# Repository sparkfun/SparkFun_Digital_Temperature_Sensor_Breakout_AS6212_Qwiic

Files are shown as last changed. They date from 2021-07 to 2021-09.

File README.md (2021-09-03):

SparkFun Digital Temperature Sensor Breakout - AS6212 (Qwiic)
========================================

SparkFun Digital Temperature Sensor Breakout - AS6212 (Qwiic) (https://www.sparkfun.com/products/18521)

[*SparkFun Digital Temperature Sensor Breakout - AS6212 (Qwiic)(SEN-18521)*](https://www.sparkfun.com/products/18521)

The AS6212 provides a combination of high temperature accuracy with excellent low power consumption using the AS6212 digital temperature sensor from ams AG. The AS6212 measures temperature with &plusmn;0.2&deg;C accuracy between -10&deg;C to 65&deg;C, consumes an average of 6&micro;A (0.1&micro;A in standby) and communicates over I<sup>2</sup>C so naturally we put it on a Qwiic breakout to add to our ever expanding Qwiic system. The sensor boasts a host of features including a configurable alert pin that can trigger when temperature data exceeds user-defined temperature thresholds. All of this in a tiny IC package measuring 1.5mm x 1mm.

The AD0 and AD1 jumpers control the I<sup>2</sup>C address as well as enabling/disabling the Alert pin. By default, these two-way jumpers connect the AD0 pin to Ground and the Alert/AD1 pin to 3.3V to enable the Alert pin and set the I<sup>2</sup>C address to 0x48. These jumpers control the address and enable/disable the Alert pin.

Repository Contents
-------------------

* **/Documentation** - Data sheets, additional product information
* **/Hardware** - Eagle design files (.brd, .sch)
* **/Production** - Production panel files (.brd)

Documentation
--------------

* **[Installing an Arduino Library Guide](https://learn.sparkfun.com/tutorials/installing-an-arduino-library)** - Basic information on how to install an Arduino library.
* **[SparkFun AS6212 Qwiic Arduino Library](https://github.com/sparkfun/SparkFun_AS6212_Qwiic_Arduino_Library)** - Arduino library for the SparkFun Digital Temperature Sensor Breakout - AS6212 (Qwiic).
* **[Qwiic AS6212 Py](https://github.com/sparkfun/Qwiic_AS6212_Py)** - Python module for the SparkFun Digital Temperature Sensor Breakout - AS6212 (Qwiic).
* **[Hookup Guide](https://learn.sparkfun.com/tutorials/digital-temperature-sensor-breakout---as6212-qwiic-hookup-guide)** - Basic hookup guide for the SparkFun Digital Temperature Sensor Breakout - AS6212 (Qwiic).

Version History
---------------

* [SEN-18521](https://www.sparkfun.com/products/18521) - Initial release of the SparkFun Digital Temperature Sensor Breakout - AS6212 (Qwiic).

License Information
-------------------

This product is _**open source**_! 

Please review the LICENSE.md file for license information. 

If you have any questions or concerns on licensing, please contact technical support on our [SparkFun forums](https://forum.sparkfun.com/viewforum.php?f=152).

Distributed as-is; no warranty is given.

- Your friends at SparkFun.

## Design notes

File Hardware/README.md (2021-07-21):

SparkFun High Precision Temperature Sensor TMP117 (Qwiic) Design Files
=====================================

The .sch and .brd files hare are Eagle CAD schematic and PCB design files from SparkFun Electronics.
A freeware version of Eagle can be found [here](http://www.cadsoftusa.com/download-eagle/freeware/).

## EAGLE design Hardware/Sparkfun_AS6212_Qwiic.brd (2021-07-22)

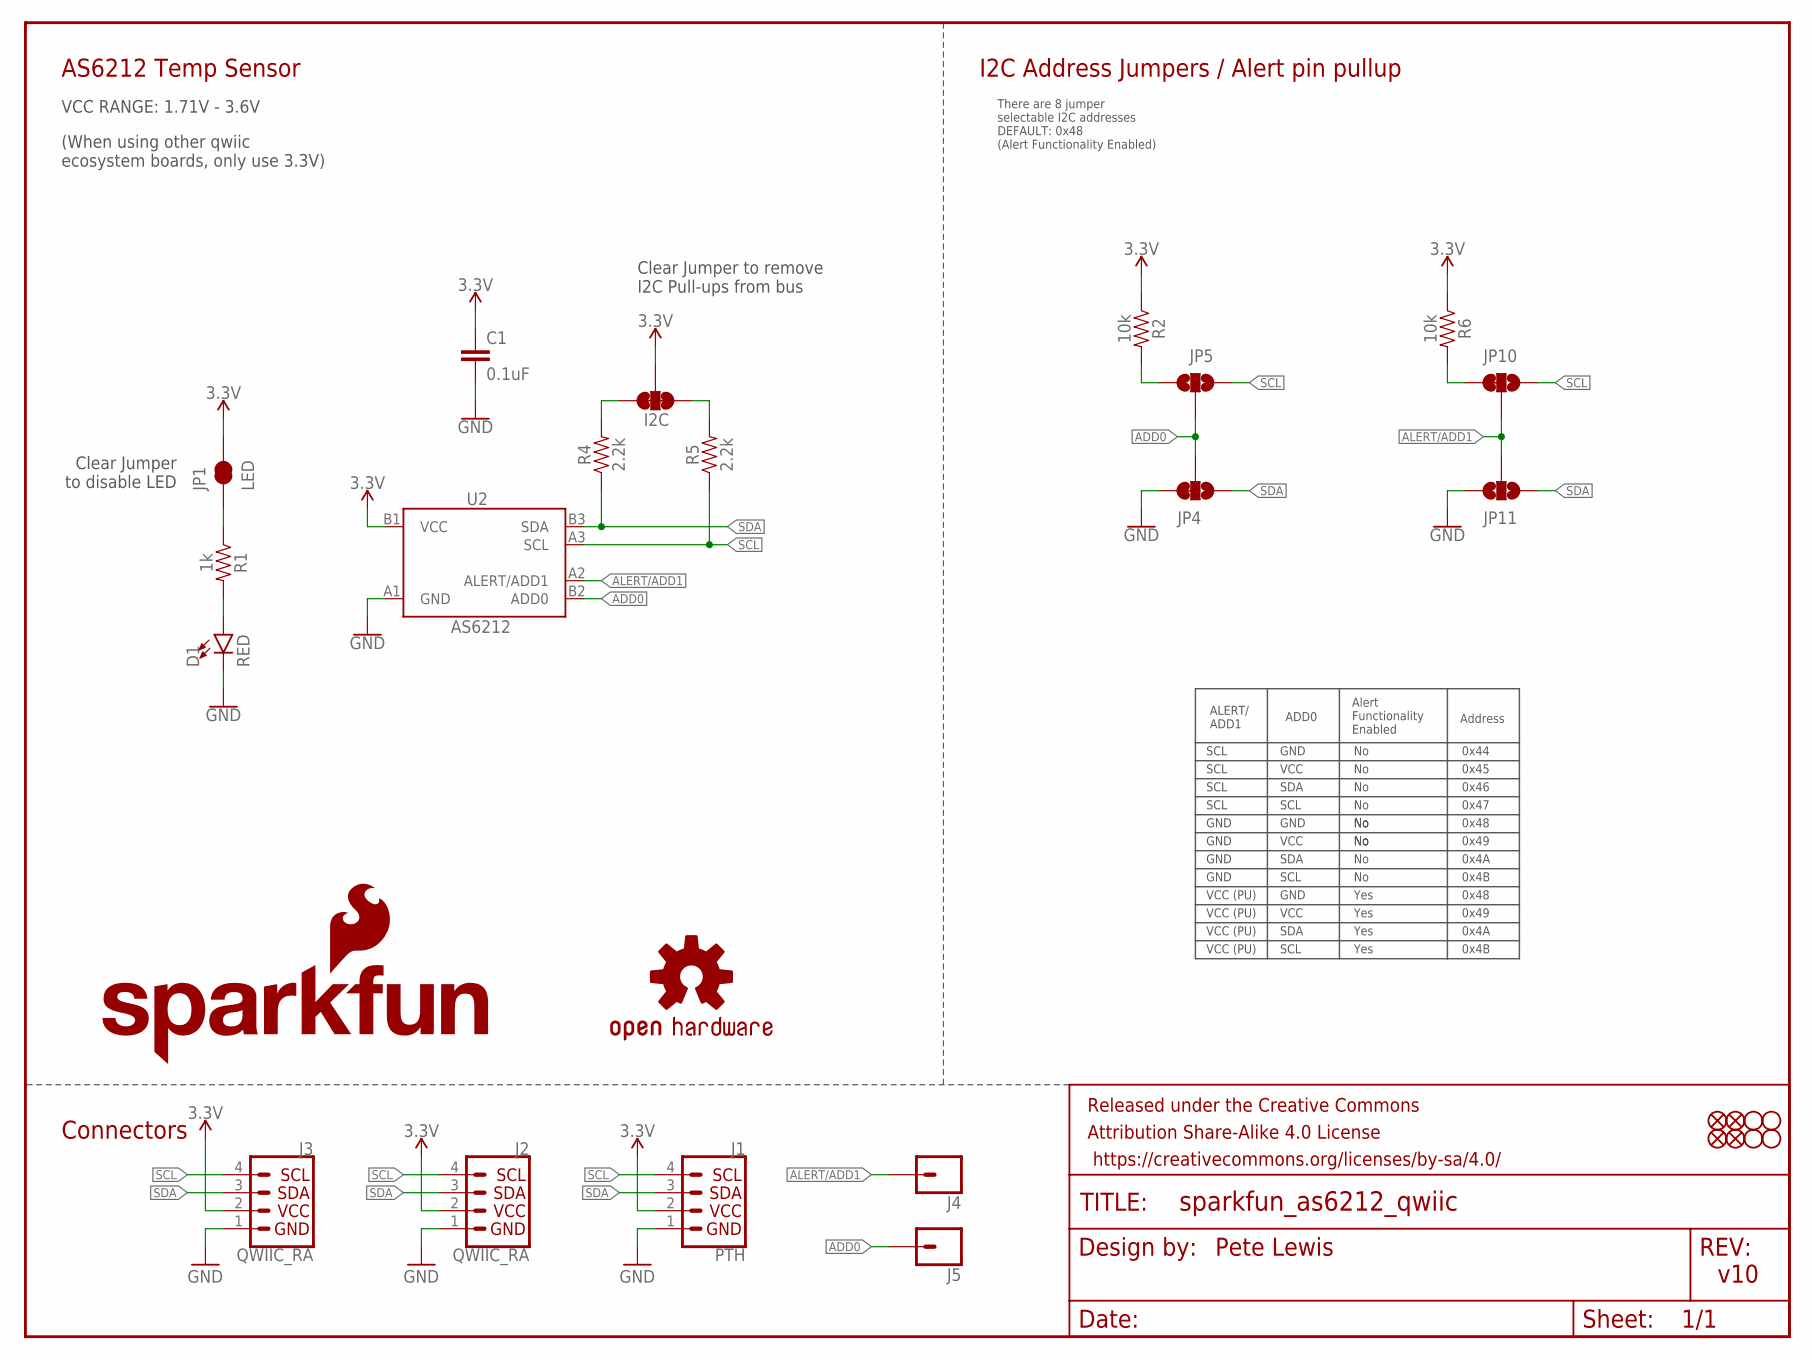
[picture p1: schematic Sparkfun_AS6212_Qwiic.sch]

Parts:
C1: 0.1uF; 0603
D1: RED; LED-0603
FD1, FD2, FD3, FD4: FIDUCIALUFIDUCIAL; FIDUCIAL-MICRO
FRAME1: FRAME-LETTER; CREATIVE_COMMONS
I2C: JUMPER-SMT_3_2-NC_TRACE_SILK; SMT-JUMPER_3_2-NC_TRACE_SILK
J1: PTH; 1X04_NO_SILK
J2, J3: QWIIC_RA; JST04_1MM_RA
J4, J5: CONN_01PTH_NO_SILK_YES_STOP; 1X01_NO_SILK
JP1: LED; SMT-JUMPER_2_NC_TRACE_SILK
JP2, JP3, JP8, JP9: STAND-OFF
JP4, JP10: JUMPER-SMT_3_1-NC_TRACE_NO-SILK; SMT-JUMPER_3_1-NC_TRACE_NO-SILK
JP5, JP11: JUMPER-SMT_3_NO_NO_SILK; SMT-JUMPER_3_0-NO_TRACE_NO-SILK
LOGO1: OSHW-LOGOMINI; OSHW-LOGO-MINI
LOGO4: SFE_LOGO_NAME_FLAME.1_INCH; SFE_LOGO_NAME_FLAME_.1
R1: 1k; 0603
R2, R6: 10k; 0603
R4, R5: 2.2k; 0603
U2: AS6212; WLCSP

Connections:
3.3V: C1.1, I2C.2, J1.2, J2.2, J3.2, JP1.2, R2.1, R6.1, U2.B1 (VCC)
ADD0: J5.1, JP4.2, JP5.2, U2.B2 (ADD0)
ALERT/ADD1: J4.1, JP10.2, JP11.2, U2.A2 (ALERT/ADD1)
GND: C1.2, D1.C, J1.1, J2.1, J3.1, JP4.3, JP11.3, U2.A1 (GND)
unnamed: D1.A, R1.2
unnamed: I2C.1, R5.2
unnamed: I2C.3, R4.2
unnamed: JP10.3, R6.2
unnamed: JP5.1, R2.2
unnamed: JP1.1, R1.1
SCL: J1.4, J2.4, J3.4, JP5.3, JP10.1, R5.1, U2.A3 (SCL)
SDA: J1.3, J2.3, J3.3, JP4.1, JP11.1, R4.1, U2.B3 (SDA)

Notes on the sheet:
Pete Lewis
Clear Jumper to remove I2C Pull-ups from bus
v10
There are 8 jumper selectable I2C addresses DEFAULT: 0x48 (Alert Functionality Enabled)
Alert Functionality Enabled
SCL
Clear Jumper to disable LED
VCC RANGE: 1.71V - 3.6V
(When using other qwiic ecosystem boards, only use 3.3V)
AS6212 Temp Sensor
I2C Address Jumpers / Alert pin pullup
Connectors
VCC (PU)
GND
ALERT/ ADD1
ADD0
SDA
VCC
Yes
Address
0x44
0x45
0x46
0x49
0x4A
0x4B
0x47
0x48

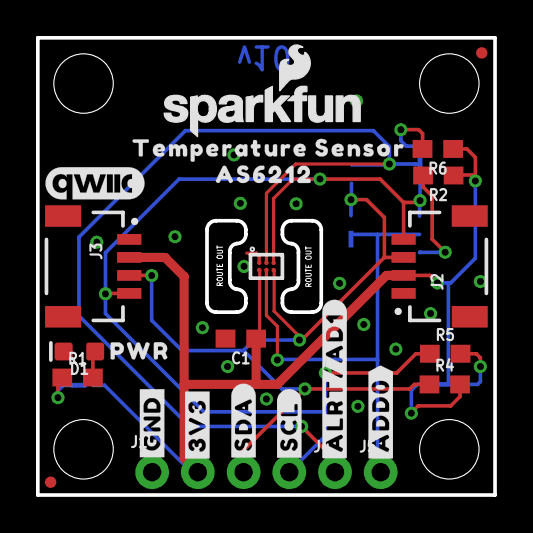
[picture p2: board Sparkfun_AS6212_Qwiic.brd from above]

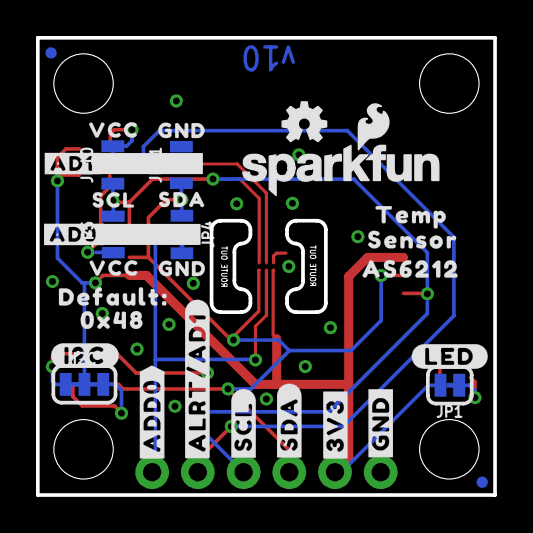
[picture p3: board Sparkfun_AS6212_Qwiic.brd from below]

Board: 2 copper layers, 25.4 x 25.4 mm, 62 parts (31 on the bottom side), 12 nets.

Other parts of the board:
LOGO2: SFE_LOGO_NAME_FLAME.1_INCH; SFE_LOGO_NAME_FLAME_.1
U$1: #LED#10
U$2: #I2C#11
U$3, U$25: AS62128
U$4: #AD0#1
U$5: #AD1#1
U$6: SCL3
U$7, U$13: VCC4
U$8: DEFAULT#11
U$9, U$14: GND5
U$10: SDA6
U$11, U$12: #ALRT#AD1#12
U$15: QWIIC_5.5MM
U$16: SENSOR8
U$17: TEMP9
U$18: 0X4812
U$19: PWR12
U$20, U$21: #3V3#13
U$24: TEMPERATURE_SENSOR7
U$26, U$30: #GND#62130
U$28, U$34: #SDA#62131
U$29, U$35: #SCL#62132
U$31, U$36: #ADD0#0

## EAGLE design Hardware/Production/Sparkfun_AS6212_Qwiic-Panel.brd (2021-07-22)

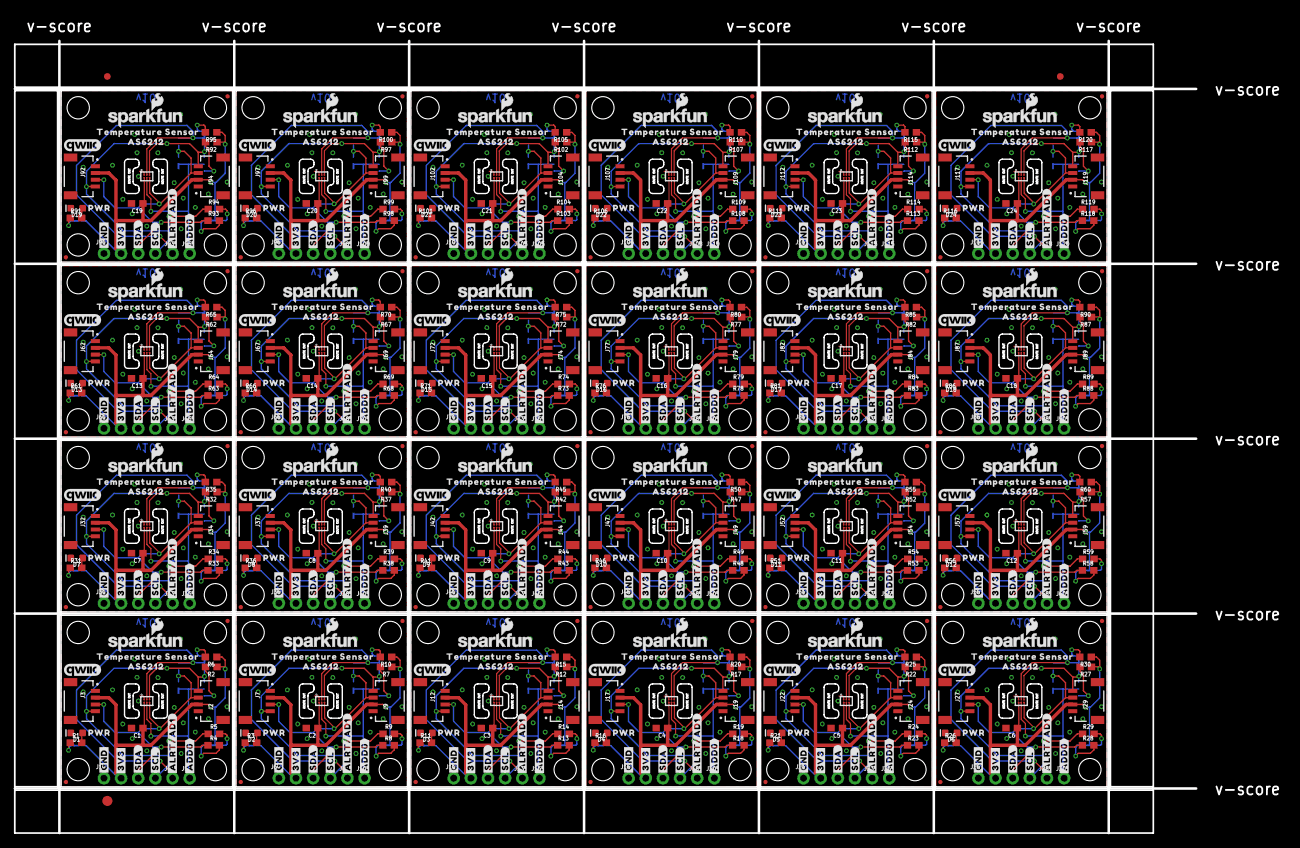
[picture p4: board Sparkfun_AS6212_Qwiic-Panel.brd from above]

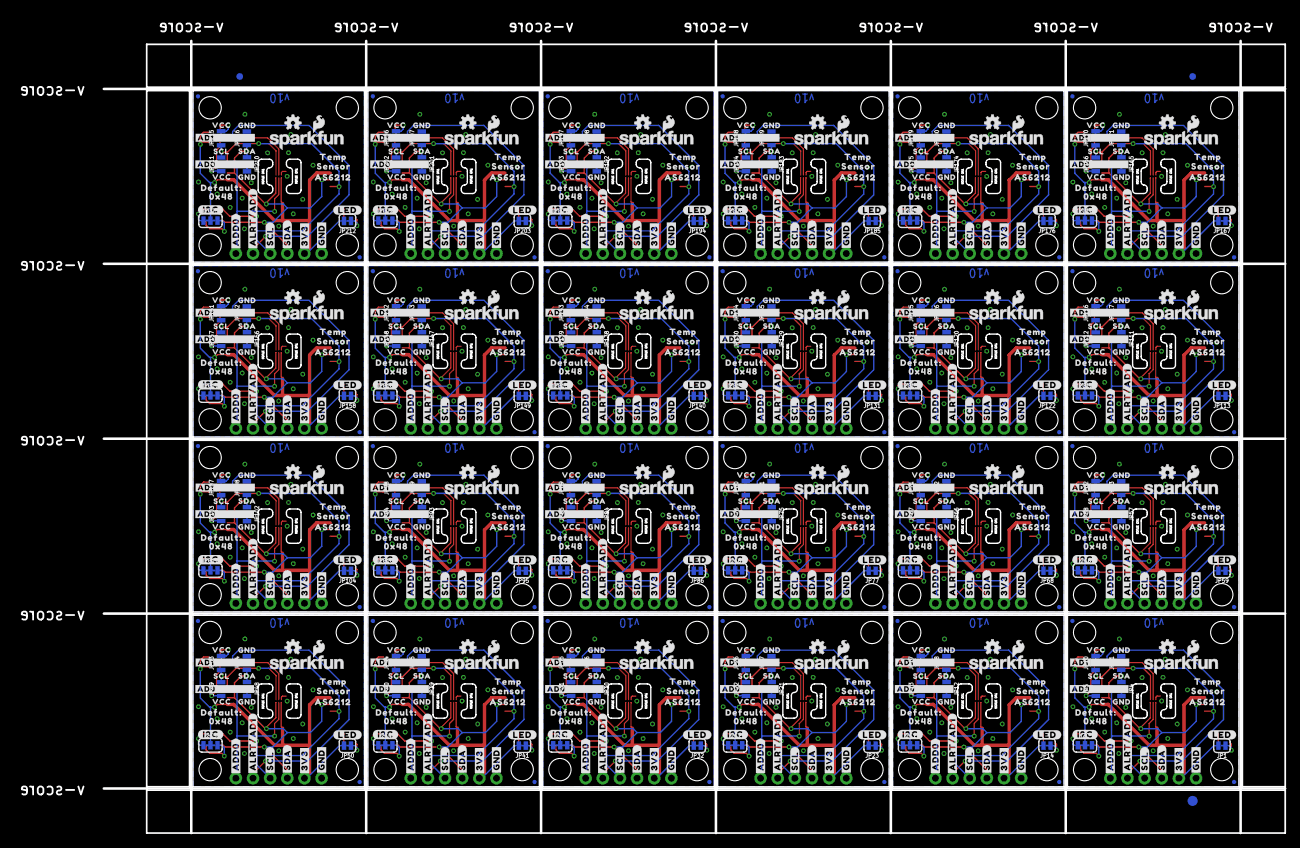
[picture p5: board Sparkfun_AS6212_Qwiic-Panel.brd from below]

Board: 2 copper layers, 175.0 x 117.3 mm, 1470 parts (747 on the bottom side), 288 nets.

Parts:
C1, C2, C3, C4, C5, C6, C7, C8, C9, C10, C11, C12, C13, C14, C15, C16, C17, C18, C19, C20, C21, C22, C23, C24: 0.1uF; 0603
D1, D2, D3, D4, D5, D6, D7, D8, D9, D10, D11, D12, D13, D14, D15, D16, D17, D18, D19, D20, D21, D22, D23, D24: RED; LED-0603
E$1, E$2, E$3, E$4: FIDUCIAL-1X2
E$5, E$6: FIDUCIAL-1.5X3
FD1, FD2, FD3, FD4, FD5, FD6, FD7, FD8, FD9, FD10, FD11, FD12, FD13, FD14, FD15, FD16, FD17, FD18, FD19, FD20, FD21, FD22, FD23, FD24, FD25, FD26, FD27, FD28, FD29, FD30, FD31, FD32, FD33, FD34, FD35, FD36, FD37, FD38, FD39, FD40, FD41, FD42, FD43, FD44, FD45, FD46, FD47, FD48, FD49, FD50, FD51, FD52, FD53, FD54, FD55, FD56, FD57, FD58, FD59, FD60, FD61, FD62, FD63, FD64, FD65, FD66, FD67, FD68, FD69, FD70, FD71, FD72, FD73, FD74, FD75, FD76, FD77, FD78, FD79, FD80, FD81, FD82, FD83, FD84, FD85, FD86, FD87, FD88, FD89, FD90, FD91, FD92, FD93, FD94, FD95, FD96: FIDUCIALUFIDUCIAL; FIDUCIAL-MICRO
I2C, I2C1, I2C2, I2C3, I2C4, I2C5, I2C6, I2C7, I2C8, I2C9, I2C10, I2C11, I2C12, I2C13, I2C14, I2C15, I2C16, I2C17, I2C18, I2C19, I2C20, I2C21, I2C22, I2C23: SMT-JUMPER_3_2-NC_TRACE_SILK
J1, J6, J11, J16, J21, J26, J31, J36, J41, J46, J51, J56, J61, J66, J71, J76, J81, J86, J91, J96, J101, J106, J111, J116: PTH; 1X04_NO_SILK
J2, J3, J7, J9, J12, J14, J17, J19, J22, J24, J27, J29, J32, J34, J37, J39, J42, J44, J47, J49, J52, J54, J57, J59, J62, J64, J67, J69, J72, J74, J77, J79, J82, J84, J87, J89, J92, J94, J97, J99, J102, J104, J107, J109, J112, J114, J117, J119: QWIIC_RA; JST04_1MM_RA
J4, J5, J8, J10, J13, J15, J18, J20, J23, J25, J28, J30, J33, J35, J38, J40, J43, J45, J48, J50, J53, J55, J58, J60, J63, J65, J68, J70, J73, J75, J78, J80, J83, J85, J88, J90, J93, J95, J98, J100, J103, J105, J108, J110, J113, J115, J118, J120: 1X01_NO_SILK
JP1, JP14, JP23, JP32, JP41, JP50, JP59, JP68, JP77, JP86, JP95, JP104, JP113, JP122, JP131, JP140, JP149, JP158, JP167, JP176, JP185, JP194, JP203, JP212: LED; SMT-JUMPER_2_NC_TRACE_SILK
JP2, JP3, JP6, JP7, JP8, JP9, JP15, JP16, JP19, JP20, JP24, JP25, JP28, JP29, JP33, JP34, JP37, JP38, JP42, JP43, JP46, JP47, JP51, JP52, JP55, JP56, JP60, JP61, JP64, JP65, JP69, JP70, JP73, JP74, JP78, JP79, JP82, JP83, JP87, JP88, JP91, JP92, JP96, JP97, JP100, JP101, JP105, JP106, JP109, JP110, JP114, JP115, JP118, JP119, JP123, JP124, JP127, JP128, JP132, JP133, JP136, JP137, JP141, JP142, JP145, JP146, JP150, JP151, JP154, JP155, JP159, JP160, JP163, JP164, JP168, JP169, JP172, JP173, JP177, JP178, JP181, JP182, JP186, JP187, JP190, JP191, JP195, JP196, JP199, JP200, JP204, JP205, JP208, JP209, JP213, JP214: STAND-OFF
JP4, JP10, JP12, JP17, JP21, JP26, JP30, JP35, JP39, JP44, JP48, JP53, JP57, JP62, JP66, JP71, JP75, JP80, JP84, JP89, JP93, JP98, JP102, JP107, JP111, JP116, JP120, JP125, JP129, JP134, JP138, JP143, JP147, JP152, JP156, JP161, JP165, JP170, JP174, JP179, JP183, JP188, JP192, JP197, JP201, JP206, JP210, JP215: JUMPER-SMT_3_1-NC_TRACE_NO-SILK; SMT-JUMPER_3_1-NC_TRACE_NO-SILK
JP5, JP11, JP13, JP18, JP22, JP27, JP31, JP36, JP40, JP45, JP49, JP54, JP58, JP63, JP67, JP72, JP76, JP81, JP85, JP90, JP94, JP99, JP103, JP108, JP112, JP117, JP121, JP126, JP130, JP135, JP139, JP144, JP148, JP153, JP157, JP162, JP166, JP171, JP175, JP180, JP184, JP189, JP193, JP198, JP202, JP207, JP211, JP216: JUMPER-SMT_3_NO_NO_SILK; SMT-JUMPER_3_0-NO_TRACE_NO-SILK
LOGO1, LOGO3, LOGO7, LOGO10, LOGO13, LOGO16, LOGO19, LOGO22, LOGO25, LOGO28, LOGO31, LOGO34, LOGO37, LOGO40, LOGO43, LOGO46, LOGO49, LOGO52, LOGO55, LOGO58, LOGO61, LOGO64, LOGO67, LOGO70: OSHW-LOGOMINI; OSHW-LOGO-MINI
LOGO2, LOGO4, LOGO5, LOGO6, LOGO8, LOGO9, LOGO11, LOGO12, LOGO14, LOGO15, LOGO17, LOGO18, LOGO20, LOGO21, LOGO23, LOGO24, LOGO26, LOGO27, LOGO29, LOGO30, LOGO32, LOGO33, LOGO35, LOGO36, LOGO38, LOGO39, LOGO41, LOGO42, LOGO44, LOGO45, LOGO47, LOGO48, LOGO50, LOGO51, LOGO53, LOGO54, LOGO56, LOGO57, LOGO59, LOGO60, LOGO62, LOGO63, LOGO65, LOGO66, LOGO68, LOGO69, LOGO71, LOGO72: SFE_LOGO_NAME_FLAME.1_INCH; SFE_LOGO_NAME_FLAME_.1
R1, R3, R11, R16, R21, R26, R31, R36, R41, R46, R51, R56, R61, R66, R71, R76, R81, R86, R91, R96, R101, R106, R111, R116: 1k; 0603
R2, R6, R7, R10, R12, R15, R17, R20, R22, R25, R27, R30, R32, R35, R37, R40, R42, R45, R47, R50, R52, R55, R57, R60, R62, R65, R67, R70, R72, R75, R77, R80, R82, R85, R87, R90, R92, R95, R97, R100, R102, R105, R107, R110, R112, R115, R117, R120: 10k; 0603
R4, R5, R8, R9, R13, R14, R18, R19, R23, R24, R28, R29, R33, R34, R38, R39, R43, R44, R48, R49, R53, R54, R58, R59, R63, R64, R68, R69, R73, R74, R78, R79, R83, R84, R88, R89, R93, R94, R98, R99, R103, R104, R108, R109, R113, R114, R118, R119: 2.2k; 0603
U1, U2, U3, U4, U5, U6, U7, U8, U9, U10, U11, U12, U13, U14, U15, U16, U17, U18, U19, U20, U21, U22, U23, U24: AS6212; WLCSP
U$1, U$54, U$85, U$116, U$147, U$178, U$209, U$240, U$271, U$302, U$333, U$364, U$395, U$426, U$457, U$488, U$519, U$550, U$581, U$612, U$643, U$674, U$705, U$736: #LED#10
U$2, U$55, U$86, U$117, U$148, U$179, U$210, U$241, U$272, U$303, U$334, U$365, U$396, U$427, U$458, U$489, U$520, U$551, U$582, U$613, U$644, U$675, U$706, U$737: #I2C#11
U$3, U$25, U$27, U$43, U$65, U$74, U$96, U$105, U$127, U$136, U$158, U$167, U$189, U$198, U$220, U$229, U$251, U$260, U$282, U$291, U$313, U$322, U$344, U$353, U$375, U$384, U$406, U$415, U$437, U$446, U$468, U$477, U$499, U$508, U$530, U$539, U$561, U$570, U$592, U$601, U$623, U$632, U$654, U$663, U$685, U$694, U$716, U$725: AS62128
U$4, U$44, U$75, U$106, U$137, U$168, U$199, U$230, U$261, U$292, U$323, U$354, U$385, U$416, U$447, U$478, U$509, U$540, U$571, U$602, U$633, U$664, U$695, U$726: #AD0#1
U$5, U$45, U$76, U$107, U$138, U$169, U$200, U$231, U$262, U$293, U$324, U$355, U$386, U$417, U$448, U$479, U$510, U$541, U$572, U$603, U$634, U$665, U$696, U$727: #AD1#1
U$6, U$46, U$77, U$108, U$139, U$170, U$201, U$232, U$263, U$294, U$325, U$356, U$387, U$418, U$449, U$480, U$511, U$542, U$573, U$604, U$635, U$666, U$697, U$728: SCL3
U$7, U$13, U$47, U$50, U$78, U$81, U$109, U$112, U$140, U$143, U$171, U$174, U$202, U$205, U$233, U$236, U$264, U$267, U$295, U$298, U$326, U$329, U$357, U$360, U$388, U$391, U$419, U$422, U$450, U$453, U$481, U$484, U$512, U$515, U$543, U$546, U$574, U$577, U$605, U$608, U$636, U$639, U$667, U$670, U$698, U$701, U$729, U$732: VCC4
U$8, U$56, U$87, U$118, U$149, U$180, U$211, U$242, U$273, U$304, U$335, U$366, U$397, U$428, U$459, U$490, U$521, U$552, U$583, U$614, U$645, U$676, U$707, U$738: DEFAULT#11
U$9, U$14, U$48, U$51, U$79, U$82, U$110, U$113, U$141, U$144, U$172, U$175, U$203, U$206, U$234, U$237, U$265, U$268, U$296, U$299, U$327, U$330, U$358, U$361, U$389, U$392, U$420, U$423, U$451, U$454, U$482, U$485, U$513, U$516, U$544, U$547, U$575, U$578, U$606, U$609, U$637, U$640, U$668, U$671, U$699, U$702, U$730, U$733: GND5
U$10, U$49, U$80, U$111, U$142, U$173, U$204, U$235, U$266, U$297, U$328, U$359, U$390, U$421, U$452, U$483, U$514, U$545, U$576, U$607, U$638, U$669, U$700, U$731: SDA6
U$11, U$12, U$58, U$59, U$89, U$90, U$120, U$121, U$151, U$152, U$182, U$183, U$213, U$214, U$244, U$245, U$275, U$276, U$306, U$307, U$337, U$338, U$368, U$369, U$399, U$400, U$430, U$431, U$461, U$462, U$492, U$493, U$523, U$524, U$554, U$555, U$585, U$586, U$616, U$617, U$647, U$648, U$678, U$679, U$709, U$710, U$740, U$741: #ALRT#AD1#12
U$15, U$22, U$63, U$94, U$125, U$156, U$187, U$218, U$249, U$280, U$311, U$342, U$373, U$404, U$435, U$466, U$497, U$528, U$559, U$590, U$621, U$652, U$683, U$714: QWIIC_5.5MM
U$16, U$52, U$83, U$114, U$145, U$176, U$207, U$238, U$269, U$300, U$331, U$362, U$393, U$424, U$455, U$486, U$517, U$548, U$579, U$610, U$641, U$672, U$703, U$734: SENSOR8
U$17, U$53, U$84, U$115, U$146, U$177, U$208, U$239, U$270, U$301, U$332, U$363, U$394, U$425, U$456, U$487, U$518, U$549, U$580, U$611, U$642, U$673, U$704, U$735: TEMP9
U$18, U$57, U$88, U$119, U$150, U$181, U$212, U$243, U$274, U$305, U$336, U$367, U$398, U$429, U$460, U$491, U$522, U$553, U$584, U$615, U$646, U$677, U$708, U$739: 0X4812
U$19, U$60, U$91, U$122, U$153, U$184, U$215, U$246, U$277, U$308, U$339, U$370, U$401, U$432, U$463, U$494, U$525, U$556, U$587, U$618, U$649, U$680, U$711, U$742: PWR12
U$20, U$21, U$61, U$62, U$92, U$93, U$123, U$124, U$154, U$155, U$185, U$186, U$216, U$217, U$247, U$248, U$278, U$279, U$309, U$310, U$340, U$341, U$371, U$372, U$402, U$403, U$433, U$434, U$464, U$465, U$495, U$496, U$526, U$527, U$557, U$558, U$588, U$589, U$619, U$620, U$650, U$651, U$681, U$682, U$712, U$713, U$743, U$744: #3V3#13
U$23, U$24, U$64, U$95, U$126, U$157, U$188, U$219, U$250, U$281, U$312, U$343, U$374, U$405, U$436, U$467, U$498, U$529, U$560, U$591, U$622, U$653, U$684, U$715: TEMPERATURE_SENSOR7
U$26, U$30, U$32, U$39, U$66, U$70, U$97, U$101, U$128, U$132, U$159, U$163, U$190, U$194, U$221, U$225, U$252, U$256, U$283, U$287, U$314, U$318, U$345, U$349, U$376, U$380, U$407, U$411, U$438, U$442, U$469, U$473, U$500, U$504, U$531, U$535, U$562, U$566, U$593, U$597, U$624, U$628, U$655, U$659, U$686, U$690, U$717, U$721: #GND#62130
U$28, U$33, U$34, U$40, U$67, U$71, U$98, U$102, U$129, U$133, U$160, U$164, U$191, U$195, U$222, U$226, U$253, U$257, U$284, U$288, U$315, U$319, U$346, U$350, U$377, U$381, U$408, U$412, U$439, U$443, U$470, U$474, U$501, U$505, U$532, U$536, U$563, U$567, U$594, U$598, U$625, U$629, U$656, U$660, U$687, U$691, U$718, U$722: #SDA#62131
U$29, U$35, U$37, U$41, U$68, U$72, U$99, U$103, U$130, U$134, U$161, U$165, U$192, U$196, U$223, U$227, U$254, U$258, U$285, U$289, U$316, U$320, U$347, U$351, U$378, U$382, U$409, U$413, U$440, U$444, U$471, U$475, U$502, U$506, U$533, U$537, U$564, U$568, U$595, U$599, U$626, U$630, U$657, U$661, U$688, U$692, U$719, U$723: #SCL#62132
U$31, U$36, U$38, U$42, U$69, U$73, U$100, U$104, U$131, U$135, U$162, U$166, U$193, U$197, U$224, U$228, U$255, U$259, U$286, U$290, U$317, U$321, U$348, U$352, U$379, U$383, U$410, U$414, U$441, U$445, U$472, U$476, U$503, U$507, U$534, U$538, U$565, U$569, U$596, U$600, U$627, U$631, U$658, U$662, U$689, U$693, U$720, U$724: #ADD0#0

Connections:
3.3V: C1.1, I2C.2, J1.2, J2.2, J3.2, JP1.2, R2.1, R6.1, U2.B1
3.3V1: C2.1, I2C1.2, J6.2, J7.2, J9.2, JP14.2, R7.1, R10.1, U1.B1
3.3V2: C3.1, I2C2.2, J11.2, J12.2, J14.2, JP23.2, R12.1, R15.1, U3.B1
3.3V3: C4.1, I2C3.2, J16.2, J17.2, J19.2, JP32.2, R17.1, R20.1, U4.B1
3.3V4: C5.1, I2C4.2, J21.2, J22.2, J24.2, JP41.2, R22.1, R25.1, U5.B1
3.3V5: C6.1, I2C5.2, J26.2, J27.2, J29.2, JP50.2, R27.1, R30.1, U6.B1
3.3V6: C7.1, I2C6.2, J31.2, J32.2, J34.2, JP59.2, R32.1, R35.1, U7.B1
3.3V7: C8.1, I2C7.2, J36.2, J37.2, J39.2, JP68.2, R37.1, R40.1, U8.B1
3.3V8: C9.1, I2C8.2, J41.2, J42.2, J44.2, JP77.2, R42.1, R45.1, U9.B1
3.3V9: C10.1, I2C9.2, J46.2, J47.2, J49.2, JP86.2, R47.1, R50.1, U10.B1
3.3V10: C11.1, I2C10.2, J51.2, J52.2, J54.2, JP95.2, R52.1, R55.1, U11.B1
3.3V11: C12.1, I2C11.2, J56.2, J57.2, J59.2, JP104.2, R57.1, R60.1, U12.B1
3.3V12: C13.1, I2C12.2, J61.2, J62.2, J64.2, JP113.2, R62.1, R65.1, U13.B1
3.3V13: C14.1, I2C13.2, J66.2, J67.2, J69.2, JP122.2, R67.1, R70.1, U14.B1
3.3V14: C15.1, I2C14.2, J71.2, J72.2, J74.2, JP131.2, R72.1, R75.1, U15.B1
3.3V15: C16.1, I2C15.2, J76.2, J77.2, J79.2, JP140.2, R77.1, R80.1, U16.B1
3.3V16: C17.1, I2C16.2, J81.2, J82.2, J84.2, JP149.2, R82.1, R85.1, U17.B1
3.3V17: C18.1, I2C17.2, J86.2, J87.2, J89.2, JP158.2, R87.1, R90.1, U18.B1
3.3V18: C19.1, I2C18.2, J91.2, J92.2, J94.2, JP167.2, R92.1, R95.1, U19.B1
3.3V19: C20.1, I2C19.2, J96.2, J97.2, J99.2, JP176.2, R97.1, R100.1, U20.B1
3.3V20: C21.1, I2C20.2, J101.2, J102.2, J104.2, JP185.2, R102.1, R105.1, U21.B1
3.3V21: C22.1, I2C21.2, J106.2, J107.2, J109.2, JP194.2, R107.1, R110.1, U22.B1
3.3V22: C23.1, I2C22.2, J111.2, J112.2, J114.2, JP203.2, R112.1, R115.1, U23.B1
3.3V23: C24.1, I2C23.2, J116.2, J117.2, J119.2, JP212.2, R117.1, R120.1, U24.B1
ADD0: J5.1, JP4.2, JP5.2, U2.B2
ADD1: J10.1, JP12.2, JP13.2, U1.B2
ADD2: J15.1, JP21.2, JP22.2, U3.B2
ADD3: J20.1, JP30.2, JP31.2, U4.B2
ADD4: J25.1, JP39.2, JP40.2, U5.B2
ADD5: J30.1, JP48.2, JP49.2, U6.B2
ADD6: J35.1, JP57.2, JP58.2, U7.B2
ADD7: J40.1, JP66.2, JP67.2, U8.B2
ADD8: J45.1, JP75.2, JP76.2, U9.B2
ADD9: J50.1, JP84.2, JP85.2, U10.B2
ADD10: J55.1, JP93.2, JP94.2, U11.B2
ADD11: J60.1, JP102.2, JP103.2, U12.B2
ADD12: J65.1, JP111.2, JP112.2, U13.B2
ADD13: J70.1, JP120.2, JP121.2, U14.B2
ADD14: J75.1, JP129.2, JP130.2, U15.B2
ADD15: J80.1, JP138.2, JP139.2, U16.B2
ADD16: J85.1, JP147.2, JP148.2, U17.B2
ADD17: J90.1, JP156.2, JP157.2, U18.B2
ADD18: J95.1, JP165.2, JP166.2, U19.B2
ADD19: J100.1, JP174.2, JP175.2, U20.B2
ADD20: J105.1, JP183.2, JP184.2, U21.B2
ADD21: J110.1, JP192.2, JP193.2, U22.B2
ADD22: J115.1, JP201.2, JP202.2, U23.B2
ADD23: J120.1, JP210.2, JP211.2, U24.B2
ALERT/ADD1: J4.1, JP10.2, JP11.2, U2.A2
ALERT/ADD2: J8.1, JP17.2, JP18.2, U1.A2
ALERT/ADD3: J13.1, JP26.2, JP27.2, U3.A2
ALERT/ADD4: J18.1, JP35.2, JP36.2, U4.A2
ALERT/ADD5: J23.1, JP44.2, JP45.2, U5.A2
ALERT/ADD6: J28.1, JP53.2, JP54.2, U6.A2
ALERT/ADD7: J33.1, JP62.2, JP63.2, U7.A2
ALERT/ADD8: J38.1, JP71.2, JP72.2, U8.A2
ALERT/ADD9: J43.1, JP80.2, JP81.2, U9.A2
ALERT/ADD10: J48.1, JP89.2, JP90.2, U10.A2
ALERT/ADD11: J53.1, JP98.2, JP99.2, U11.A2
ALERT/ADD12: J58.1, JP107.2, JP108.2, U12.A2
ALERT/ADD13: J63.1, JP116.2, JP117.2, U13.A2
ALERT/ADD14: J68.1, JP125.2, JP126.2, U14.A2
ALERT/ADD15: J73.1, JP134.2, JP135.2, U15.A2
ALERT/ADD16: J78.1, JP143.2, JP144.2, U16.A2
ALERT/ADD17: J83.1, JP152.2, JP153.2, U17.A2
ALERT/ADD18: J88.1, JP161.2, JP162.2, U18.A2
ALERT/ADD19: J93.1, JP170.2, JP171.2, U19.A2
ALERT/ADD20: J98.1, JP179.2, JP180.2, U20.A2
ALERT/ADD21: J103.1, JP188.2, JP189.2, U21.A2
ALERT/ADD22: J108.1, JP197.2, JP198.2, U22.A2
ALERT/ADD23: J113.1, JP206.2, JP207.2, U23.A2
ALERT/ADD24: J118.1, JP215.2, JP216.2, U24.A2
GND: C1.2, D1.C, J1.1, J2.1, J3.1, JP4.3, JP11.3, U2.A1
GND1: C2.2, D2.C, J6.1, J7.1, J9.1, JP12.3, JP18.3, U1.A1
GND2: C3.2, D3.C, J11.1, J12.1, J14.1, JP21.3, JP27.3, U3.A1
GND3: C4.2, D4.C, J16.1, J17.1, J19.1, JP30.3, JP36.3, U4.A1
GND4: C5.2, D5.C, J21.1, J22.1, J24.1, JP39.3, JP45.3, U5.A1
GND5: C6.2, D6.C, J26.1, J27.1, J29.1, JP48.3, JP54.3, U6.A1
GND6: C7.2, D7.C, J31.1, J32.1, J34.1, JP57.3, JP63.3, U7.A1
GND7: C8.2, D8.C, J36.1, J37.1, J39.1, JP66.3, JP72.3, U8.A1
GND8: C9.2, D9.C, J41.1, J42.1, J44.1, JP75.3, JP81.3, U9.A1
GND9: C10.2, D10.C, J46.1, J47.1, J49.1, JP84.3, JP90.3, U10.A1
GND10: C11.2, D11.C, J51.1, J52.1, J54.1, JP93.3, JP99.3, U11.A1
GND11: C12.2, D12.C, J56.1, J57.1, J59.1, JP102.3, JP108.3, U12.A1
GND12: C13.2, D13.C, J61.1, J62.1, J64.1, JP111.3, JP117.3, U13.A1
GND13: C14.2, D14.C, J66.1, J67.1, J69.1, JP120.3, JP126.3, U14.A1
GND14: C15.2, D15.C, J71.1, J72.1, J74.1, JP129.3, JP135.3, U15.A1
GND15: C16.2, D16.C, J76.1, J77.1, J79.1, JP138.3, JP144.3, U16.A1
GND16: C17.2, D17.C, J81.1, J82.1, J84.1, JP147.3, JP153.3, U17.A1
GND17: C18.2, D18.C, J86.1, J87.1, J89.1, JP156.3, JP162.3, U18.A1
GND18: C19.2, D19.C, J91.1, J92.1, J94.1, JP165.3, JP171.3, U19.A1
GND19: C20.2, D20.C, J96.1, J97.1, J99.1, JP174.3, JP180.3, U20.A1
GND20: C21.2, D21.C, J101.1, J102.1, J104.1, JP183.3, JP189.3, U21.A1
GND21: C22.2, D22.C, J106.1, J107.1, J109.1, JP192.3, JP198.3, U22.A1
GND22: C23.2, D23.C, J111.1, J112.1, J114.1, JP201.3, JP207.3, U23.A1
GND23: C24.2, D24.C, J116.1, J117.1, J119.1, JP210.3, JP216.3, U24.A1
unnamed: D1.A, R1.2
unnamed: I2C.1, R5.2
unnamed: I2C.3, R4.2
unnamed: D2.A, R3.2
unnamed: JP10.3, R6.2
unnamed: I2C1.1, R9.2
unnamed: JP5.1, R2.2
unnamed: JP1.1, R1.1
unnamed: I2C1.3, R8.2
unnamed: JP13.1, R7.2
unnamed: JP14.1, R3.1
unnamed: JP17.3, R10.2
unnamed: D3.A, R11.2
unnamed: I2C2.1, R14.2
unnamed: I2C2.3, R13.2
unnamed: JP22.1, R12.2
unnamed: JP23.1, R11.1
unnamed: JP26.3, R15.2
unnamed: D4.A, R16.2
unnamed: I2C3.1, R19.2
unnamed: I2C3.3, R18.2
unnamed: JP31.1, R17.2
unnamed: JP32.1, R16.1
unnamed: JP35.3, R20.2
unnamed: D5.A, R21.2
unnamed: I2C4.1, R24.2
unnamed: I2C4.3, R23.2
unnamed: JP40.1, R22.2
unnamed: JP41.1, R21.1
unnamed: JP44.3, R25.2
unnamed: D6.A, R26.2
unnamed: I2C5.1, R29.2
unnamed: I2C5.3, R28.2
unnamed: JP49.1, R27.2
unnamed: JP50.1, R26.1
unnamed: JP53.3, R30.2
unnamed: D7.A, R31.2
unnamed: I2C6.1, R34.2
unnamed: I2C6.3, R33.2
unnamed: JP58.1, R32.2
unnamed: JP59.1, R31.1
unnamed: JP62.3, R35.2
unnamed: D8.A, R36.2
unnamed: I2C7.1, R39.2
unnamed: I2C7.3, R38.2
unnamed: JP67.1, R37.2
unnamed: JP68.1, R36.1
unnamed: JP71.3, R40.2
unnamed: D9.A, R41.2
unnamed: I2C8.1, R44.2
unnamed: I2C8.3, R43.2
unnamed: JP76.1, R42.2
unnamed: JP77.1, R41.1
unnamed: JP80.3, R45.2
unnamed: D10.A, R46.2
unnamed: I2C9.1, R49.2
unnamed: I2C9.3, R48.2
unnamed: JP85.1, R47.2
unnamed: JP86.1, R46.1
unnamed: JP89.3, R50.2
unnamed: D11.A, R51.2
unnamed: I2C10.1, R54.2
unnamed: I2C10.3, R53.2
unnamed: JP94.1, R52.2
unnamed: JP95.1, R51.1
unnamed: JP98.3, R55.2
unnamed: D12.A, R56.2
unnamed: I2C11.1, R59.2
unnamed: I2C11.3, R58.2
unnamed: JP103.1, R57.2
unnamed: JP104.1, R56.1
unnamed: JP107.3, R60.2
unnamed: D13.A, R61.2
unnamed: I2C12.1, R64.2
unnamed: I2C12.3, R63.2
unnamed: JP112.1, R62.2
unnamed: JP113.1, R61.1
unnamed: JP116.3, R65.2
unnamed: D14.A, R66.2
unnamed: I2C13.1, R69.2
unnamed: I2C13.3, R68.2
unnamed: JP121.1, R67.2
unnamed: JP122.1, R66.1
unnamed: JP125.3, R70.2
unnamed: D15.A, R71.2
unnamed: I2C14.1, R74.2
unnamed: I2C14.3, R73.2
unnamed: JP130.1, R72.2
unnamed: JP131.1, R71.1
unnamed: JP134.3, R75.2
unnamed: D16.A, R76.2
unnamed: I2C15.1, R79.2
unnamed: I2C15.3, R78.2
unnamed: JP139.1, R77.2
unnamed: JP140.1, R76.1
unnamed: JP143.3, R80.2
unnamed: D17.A, R81.2
unnamed: I2C16.1, R84.2
unnamed: I2C16.3, R83.2
unnamed: JP148.1, R82.2
unnamed: JP149.1, R81.1
unnamed: JP152.3, R85.2
unnamed: D18.A, R86.2
unnamed: I2C17.1, R89.2
unnamed: I2C17.3, R88.2
unnamed: JP157.1, R87.2
unnamed: JP158.1, R86.1
unnamed: JP161.3, R90.2
unnamed: D19.A, R91.2
unnamed: I2C18.1, R94.2
unnamed: I2C18.3, R93.2
unnamed: JP166.1, R92.2
unnamed: JP167.1, R91.1
unnamed: JP170.3, R95.2
unnamed: D20.A, R96.2
unnamed: I2C19.1, R99.2
unnamed: I2C19.3, R98.2
unnamed: JP175.1, R97.2
unnamed: JP176.1, R96.1
unnamed: JP179.3, R100.2
unnamed: D21.A, R101.2
unnamed: I2C20.1, R104.2
unnamed: I2C20.3, R103.2
unnamed: JP184.1, R102.2
unnamed: JP185.1, R101.1
unnamed: JP188.3, R105.2
unnamed: D22.A, R106.2
unnamed: I2C21.1, R109.2
unnamed: I2C21.3, R108.2
unnamed: JP193.1, R107.2
unnamed: JP194.1, R106.1
unnamed: JP197.3, R110.2
unnamed: D23.A, R111.2
unnamed: I2C22.1, R114.2
unnamed: I2C22.3, R113.2
unnamed: JP202.1, R112.2
unnamed: JP203.1, R111.1
unnamed: JP206.3, R115.2
unnamed: D24.A, R116.2
unnamed: I2C23.1, R119.2
unnamed: I2C23.3, R118.2
unnamed: JP211.1, R117.2
unnamed: JP212.1, R116.1
unnamed: JP215.3, R120.2
SCL: J1.4, J2.4, J3.4, JP5.3, JP10.1, R5.1, U2.A3
SCL1: J6.4, J7.4, J9.4, JP13.3, JP17.1, R9.1, U1.A3
SCL2: J11.4, J12.4, J14.4, JP22.3, JP26.1, R14.1, U3.A3
SCL3: J16.4, J17.4, J19.4, JP31.3, JP35.1, R19.1, U4.A3
SCL4: J21.4, J22.4, J24.4, JP40.3, JP44.1, R24.1, U5.A3
SCL5: J26.4, J27.4, J29.4, JP49.3, JP53.1, R29.1, U6.A3
SCL6: J31.4, J32.4, J34.4, JP58.3, JP62.1, R34.1, U7.A3
SCL7: J36.4, J37.4, J39.4, JP67.3, JP71.1, R39.1, U8.A3
SCL8: J41.4, J42.4, J44.4, JP76.3, JP80.1, R44.1, U9.A3
SCL9: J46.4, J47.4, J49.4, JP85.3, JP89.1, R49.1, U10.A3
SCL10: J51.4, J52.4, J54.4, JP94.3, JP98.1, R54.1, U11.A3
SCL11: J56.4, J57.4, J59.4, JP103.3, JP107.1, R59.1, U12.A3
SCL12: J61.4, J62.4, J64.4, JP112.3, JP116.1, R64.1, U13.A3
SCL13: J66.4, J67.4, J69.4, JP121.3, JP125.1, R69.1, U14.A3
SCL14: J71.4, J72.4, J74.4, JP130.3, JP134.1, R74.1, U15.A3
SCL15: J76.4, J77.4, J79.4, JP139.3, JP143.1, R79.1, U16.A3
SCL16: J81.4, J82.4, J84.4, JP148.3, JP152.1, R84.1, U17.A3
SCL17: J86.4, J87.4, J89.4, JP157.3, JP161.1, R89.1, U18.A3
SCL18: J91.4, J92.4, J94.4, JP166.3, JP170.1, R94.1, U19.A3
SCL19: J96.4, J97.4, J99.4, JP175.3, JP179.1, R99.1, U20.A3
SCL20: J101.4, J102.4, J104.4, JP184.3, JP188.1, R104.1, U21.A3
SCL21: J106.4, J107.4, J109.4, JP193.3, JP197.1, R109.1, U22.A3
SCL22: J111.4, J112.4, J114.4, JP202.3, JP206.1, R114.1, U23.A3
SCL23: J116.4, J117.4, J119.4, JP211.3, JP215.1, R119.1, U24.A3
SDA: J1.3, J2.3, J3.3, JP4.1, JP11.1, R4.1, U2.B3
SDA1: J6.3, J7.3, J9.3, JP12.1, JP18.1, R8.1, U1.B3
SDA2: J11.3, J12.3, J14.3, JP21.1, JP27.1, R13.1, U3.B3
SDA3: J16.3, J17.3, J19.3, JP30.1, JP36.1, R18.1, U4.B3
SDA4: J21.3, J22.3, J24.3, JP39.1, JP45.1, R23.1, U5.B3
SDA5: J26.3, J27.3, J29.3, JP48.1, JP54.1, R28.1, U6.B3
SDA6: J31.3, J32.3, J34.3, JP57.1, JP63.1, R33.1, U7.B3
SDA7: J36.3, J37.3, J39.3, JP66.1, JP72.1, R38.1, U8.B3
SDA8: J41.3, J42.3, J44.3, JP75.1, JP81.1, R43.1, U9.B3
SDA9: J46.3, J47.3, J49.3, JP84.1, JP90.1, R48.1, U10.B3
SDA10: J51.3, J52.3, J54.3, JP93.1, JP99.1, R53.1, U11.B3
SDA11: J56.3, J57.3, J59.3, JP102.1, JP108.1, R58.1, U12.B3
SDA12: J61.3, J62.3, J64.3, JP111.1, JP117.1, R63.1, U13.B3
SDA13: J66.3, J67.3, J69.3, JP120.1, JP126.1, R68.1, U14.B3
SDA14: J71.3, J72.3, J74.3, JP129.1, JP135.1, R73.1, U15.B3
SDA15: J76.3, J77.3, J79.3, JP138.1, JP144.1, R78.1, U16.B3
SDA16: J81.3, J82.3, J84.3, JP147.1, JP153.1, R83.1, U17.B3
SDA17: J86.3, J87.3, J89.3, JP156.1, JP162.1, R88.1, U18.B3
SDA18: J91.3, J92.3, J94.3, JP165.1, JP171.1, R93.1, U19.B3
SDA19: J96.3, J97.3, J99.3, JP174.1, JP180.1, R98.1, U20.B3
SDA20: J101.3, J102.3, J104.3, JP183.1, JP189.1, R103.1, U21.B3
SDA21: J106.3, J107.3, J109.3, JP192.1, JP198.1, R108.1, U22.B3
SDA22: J111.3, J112.3, J114.3, JP201.1, JP207.1, R113.1, U23.B3
SDA23: J116.3, J117.3, J119.3, JP210.1, JP216.1, R118.1, U24.B3

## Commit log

2021-07-21 Layout started
    [Sparkfun_AS6212_Qwiic.brd, Sparkfun_AS6212_Qwiic.sch]
2021-07-21 Layout ready for review
    [Sparkfun_AS6212_Qwiic.brd, Sparkfun_AS6212_Qwiic.sch]
2021-07-22 my run of checklist catches
    -silk outline of IC package increased to 8 mil
    -approved DRC errors
    -re-routed off IS to allow GND flow
    -more GND stiching vias
    -nudged some resistors away from standoff screw head
    -updated 3-pad jumpers to latest in library to avoid access DRC errors
    -added measures
    [Sparkfun_AS6212_Qwiic.brd, Sparkfun_AS6212_Qwiic.sch]
2021-07-22 design review group
    -adjusted some traces and added more GND vias for return currents
    -changed to 3V3 on label to avoid dot not printing nice
    -GND symbols updated to new libraries
    [Sparkfun_AS6212_Qwiic.brd, Sparkfun_AS6212_Qwiic.sch]
2021-07-22 removed old milling stuff for air gaps
    [Sparkfun_AS6212_Qwiic.brd]
2021-07-22 nudged LED and I2C jumpers away from standoffs a tiny bit.
    [Sparkfun_AS6212_Qwiic.brd]
2021-07-22 Production panel and gerbers v10
    [Sparkfun_AS6212_Qwiic-Panel.brd]

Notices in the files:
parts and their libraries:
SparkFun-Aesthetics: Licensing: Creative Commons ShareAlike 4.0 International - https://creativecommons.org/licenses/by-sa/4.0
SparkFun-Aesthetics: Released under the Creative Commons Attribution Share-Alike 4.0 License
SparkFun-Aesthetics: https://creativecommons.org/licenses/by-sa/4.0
